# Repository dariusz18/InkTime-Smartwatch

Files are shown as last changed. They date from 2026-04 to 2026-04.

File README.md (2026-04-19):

# Documentatie Tehnica Hardware - InkTime Smartwatch

Acest repository contine fisierele de proiectare hardware pentru InkTime, un dispozitiv purtabil bazat pe arhitectura nRF52840, optimizat pentru eficienta energetica ridicata si afisaj bi-stabil.

## 1. Descriere Functionalitate Hardware

Sistemul electronic este proiectat modular, avand urmatoarele subsisteme critice:

* **Unitatea Centrala de Procesare (MCU):** Proiectul utilizeaza SoC-ul **nRF52840** (Nordic Semiconductor), ales pentru suportul nativ Bluetooth 5.0 si consumul minim in modurile de repaus. Acesta gestioneaza comunicarea cu senzorii si controlul refresh-ului pentru display.
* **Modulul de Afisaj (E-Paper):** Dispozitivul integreaza un ecran tip Electronic Paper (e-Ink). Circuitul de comanda include un convertor de tip "boost" (format din inductanta de 68uH, diode Schottky si tranzistori MOSFET) necesar pentru generarea tensiunilor de polarizare specifice tehnologiei electroforetice.
* **Managementul Alimentarii (PMU):** * **LiPo Charger:** Incarcarea acumulatorului este gestionata de un controller dedicat, configurat pentru curent de incarcare sigur.
    * **DC/DC Converter:** Asigura conversia tensiunii bateriei la pragul stabil de 3.3V necesar rail-ului digital.
    * **Fuel Gauge:** Integratul MAX17048 monitorizeaza starea de sanatate a bateriei si transmite datele prin I2C.
* **Interfata cu Utilizatorul:** Sistemul include trei butoane mecanice conectate la pini GPIO cu pull-up intern si un driver haptic pentru semnalizarea evenimentelor prin vibratii.

## 2. Diagrama Bloc si Conectivitate

Arhitectura sistemului urmeaza fluxul: **Sursa Energie -> PMU -> MCU -> Periferice (Display/IMU)**.

### Tabel Conectare Pini nRF52840

| Periferic | Protocol Comunicare | Pini Alocati (MCU) |
| :--- | :--- | :--- |
| **E-Paper Display** | SPI (MOSI, SCK, CS) | P0.26, P0.27 (DC), P0.28 (RES) |
| **IMU / Fuel Gauge** | I2C (SDA, SCL) | P0.11, P0.12 |
| **Haptic Motor** | PWM | P0.14 |
| **Butoane (Up/Ent/Dn)** | Digital Input | P0.09, P0.10, P0.24 |
| **Programare/Debug** | SWD | SWDIO, SWDCLK |

## 3. Implementare Mecanica si Proiectare 3D

Carcasa proiectata in Autodesk Fusion asigura protectia mecanica a ansamblului. Proiectarea a tinut cont de:
* Pozitionarea antenei nRF52840 departe de planul de masa pentru semnal optim.
* Asamblarea tip "sandwich" a componentelor: Ecran -> PCB -> Baterie.
* Accesul extern pentru portul de incarcare USB-C, protejat prin circuite de suprimare a tensiunilor tranzitorii (TVS/ESD).

### Review Tehnologic: Avantajele tehnologiei E-Paper
Alegerea unui afisaj de tip E-Paper ofera dispozitivului o autonomie superioara. Datorita proprietatii de bi-stabilitate, pixelii isi mentin starea fara consum de energie. Consumul de curent are loc exclusiv in timpul tranzitiilor de stare (refresh), permitand MCU-ului sa ramana in mod "Deep Sleep" majoritatea timpului. Aceasta abordare elimina necesitatea unei iluminari de fundal (Backlight), vizibilitatea fiind direct proportionala cu lumina ambientala.

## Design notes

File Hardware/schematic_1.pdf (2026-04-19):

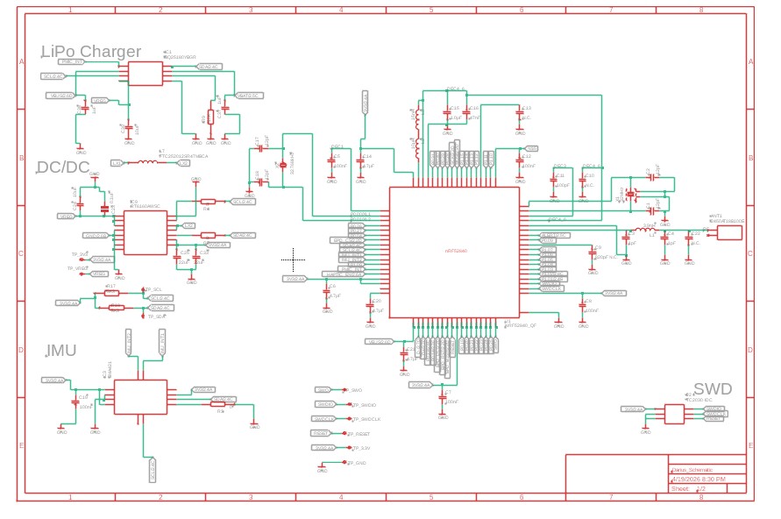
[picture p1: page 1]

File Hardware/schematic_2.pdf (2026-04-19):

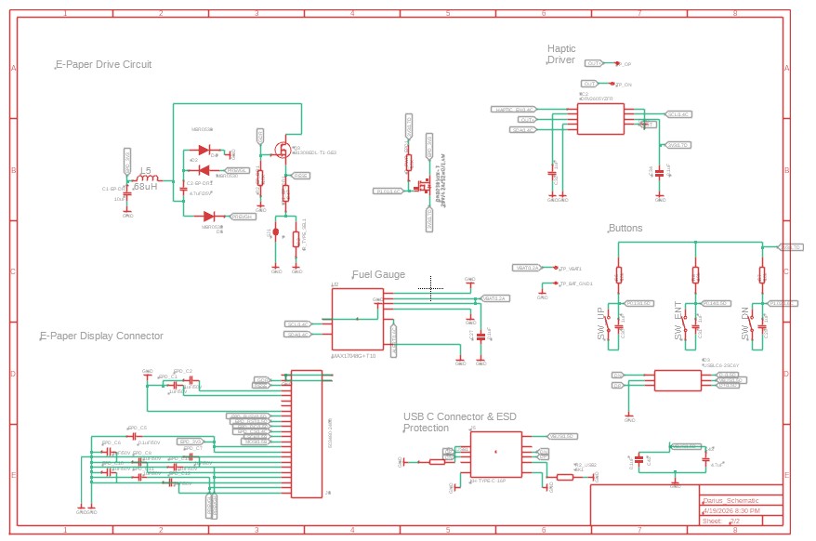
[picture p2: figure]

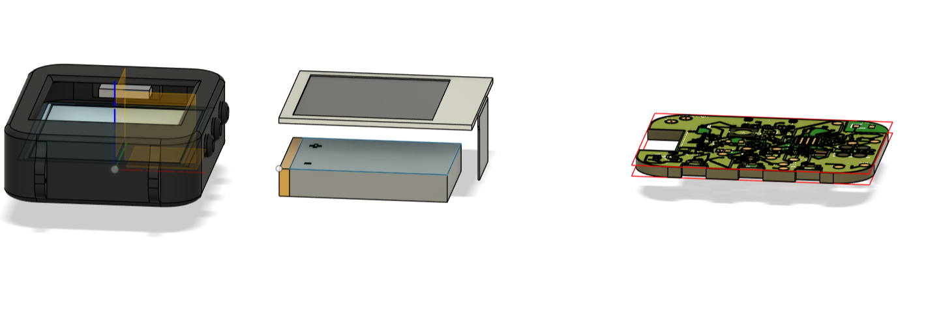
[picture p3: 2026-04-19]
Images/Screenshot 2026-04-20 000259.png

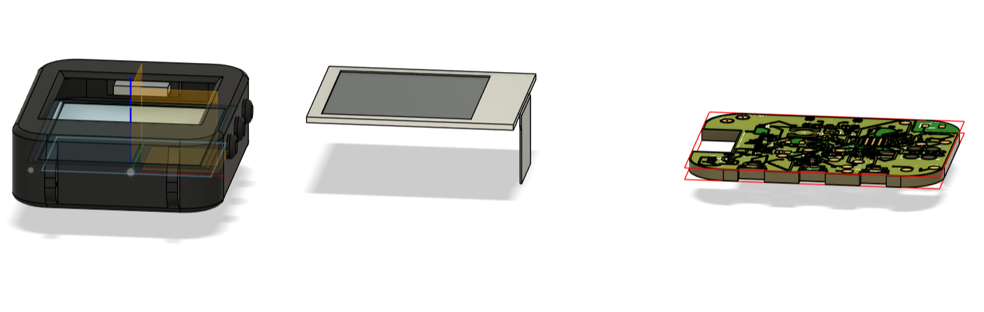
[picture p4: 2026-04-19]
Images/Screenshot 2026-04-20 000249.png

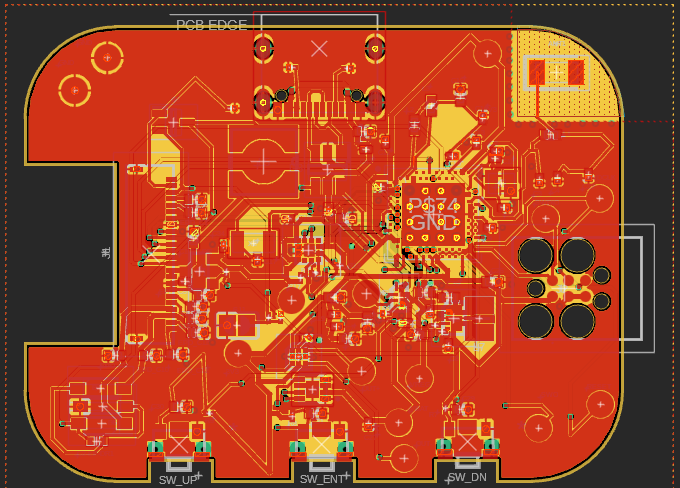
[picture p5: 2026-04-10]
Images/pcb.png

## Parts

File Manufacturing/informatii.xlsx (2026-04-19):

Name | Zaharescu
Exported by | darius.zaharescu@stud.acs.upb.ro
Time of Export | 4/20/2026 12:54 AM
Reference Designators | Quantity | Description | Package | Value | Manufacturer | Manufacturer Part Number | Vendor | Vendor Part Number | Top/Bottom
 | 1 | PCB Board | Board
ANT1 | 1 | 2450AT18B100E-1 | 2450AT18B100E_ANTC3216X140N | 2450AT18B100E |  |  |  |  | Top
C1, C2, C17, C18 | 4 | 0201 chip | NORDIC_NRF_3_RESC0201_L | 12pF |  |  |  |  | Top
C1-EP-DR, C24, C39 | 3 | 0402 chip | NORDIC_NRF_3_RESC0402_L | 10uF |  |  |  |  | Top
C2-EP-DR1 | 1 | 0402 chip | NORDIC_NRF_3_RESC0402_L | 4.7uF/25V |  |  |  |  | Top
C3, C4 | 2 | 0201 chip | NORDIC_NRF_3_RESC0201_L | 1pF |  |  |  |  | Top
C5, C7, C8, C12, C19 | 5 | 0201 chip | NORDIC_NRF_3_RESC0201_L | 100nF |  |  |  |  | Top
C6, C14, C20, C21 | 4 | 0402 chip | NORDIC_NRF_3_RESC0402_L | 4.7µF |  |  |  |  | Top
C9 | 1 | 0201 chip | NORDIC_NRF_3_RESC0201_L | 820pF |  |  |  |  | Top
C10, C13 | 2 | 0201 chip | NORDIC_NRF_3_RESC0201_L |  |  |  |  |  | Top
C11 | 1 | 0201 chip | NORDIC_NRF_3_RESC0201_L | 100pF |  |  |  |  | Top
C15 | 1 | 0402 chip | NORDIC_NRF_3_RESC0402_L | 1.0µF |  |  |  |  | Top
C16 | 1 | 0201 chip | NORDIC_NRF_3_RESC0201_L | 47nF |  |  |  |  | Top
C22 | 1 | 0201 chip | NORDIC_NRF_3_RESC0201_L | N.C. |  |  |  |  | Top
C23, C27, C42 | 3 | 0201 chip | NORDIC_NRF_3_RESC0201_L | 0.1uF |  |  |  |  | Top
C25, C33 | 2 | 0402 chip | NORDIC_NRF_3_RESC0402_L | 22uF |  |  |  |  | Top
C29, C30, C31 | 3 | 0402 chip | NORDIC_NRF_3_RESC0402_L | 1uF |  |  |  |  | Top
C32, C37, C38 | 3 |  | GRM011R60J152KE01L_2_CAPC0201X13N | 1uF |  |  |  |  | Top
C34 | 1 |  | GRM011R60J152KE01L_2_CAPC0201X13N | 0.1uF |  |  |  |  | Top
C43 | 1 | 0402 chip | NORDIC_NRF_3_RESC0402_L | 4.7uF |  |  |  |  | Top
D2, D4, D5 | 3 | SOD-123 CASE425-04 ISSUE G | ESP32_C6_LIBRARY_5_SOD3716X135N | MBR0530 |  |  |  |  | Top
D3 | 1 | SOT23-6(ESDA6V1-5SC6Y) | ESP32_C6_LIBRARY_3_SOT95P280X145-6N | USBLC6-2SC6Y |  |  |  |  | Top
EPD_C1, EPD_C2, EPD_C6, EPD_C7, EPD_C8, EPD_C9, EPD_C10, EPD_C11, EPD_C12 | 9 | 0402 chip | NORDIC_NRF_3_RESC0402_L | 1uF/50V |  |  |  |  | Top
EPD_C5 | 1 | 0201 chip | NORDIC_NRF_3_RESC0201_L | 0.1uF/50V |  |  |  |  | Top
IC1 | 1 | YBG0008 | BQ25180YBGR_BGA8C40P2X4_100X155X50 | BQ25180YBGR |  |  |  |  | Top
IC2 | 1 | DRV2605YZFR_1 | DRV2605YZFR_BGA9C50P3X3_144X144X62 | DRV2605YZFR |  |  |  |  | Top
IC3 | 1 | BMA423-1 | BMA423_BMA423 | BMA423 |  |  |  |  | Top
IC9 | 1 | 15B WL-CSP 1.4x2.3 Package (BSC) | RT6160AWSC_BGA15C40P3X5_140X230X60 | RT6160AWSC |  |  |  |  | Top
J1 | 1 | 503480-2400-2 | 503480-2400_5034802400 | 503480-2400 |  |  |  |  | Top
J2 | 1 | TC2030-IDC | TC2030-IDC_TC2030IDC | TC2030-IDC |  |  |  |  | Top
J4 | 1 |  | KH-TYPE-C-16P_KINGHELM_KH-TYPE-C-16P | KH-TYPE-C-16P |  |  |  |  | Top
L1 | 1 | 0402 chip | NORDIC_NRF_2_RESC0402_L | 3.9nH |  |  |  |  | Top
L2 | 1 | 0402 chip | NORDIC_NRF_2_RESC0402_L | 10µH |  |  |  |  | Top
L3 | 1 | 0402 chip | NORDIC_NRF_2_RESC0402_L | 15nF |  |  |  |  | Top
L5 | 1 |  | ESP32_C6_LIBRARY_2_IND_4828-WE-TPC_WRE | 68uH |  |  |  |  | Top
L7 | 1 | MLP2016 | MLP2016SR47MT0S1_INDC2016X100N | FTC252012SR47MBCA |  |  |  |  | Top
Q1 | 1 | SOT23-3X | ESP32_C6_LIBRARY_4_ESP32_C6_LIBRARY_4_ESP32_C6_LIBRARY_4_ESP32_C6_LIBRARY_4_ESP32_WROVER_SPARKFUN-DISCRETESEMI_SOT23-3 | 20V/4.2A/52mΩ/1.4W |  |  |  |  | Top
Q3 | 1 | SC-70_3LEADS | ESP32_C6_LIBRARY_6_SOT65P210X110-3N | SI1308EDL-T1-GE3 |  |  |  |  | Top
R_PWR_EPD, R2_EP_DR, R9 | 3 |  | CPF0201D7K68C1_0201 | 10K |  |  |  |  | Top
R_TYPE_SEL | 1 |  | CPF0201D7K68C1_0201 | 2.2 |  |  |  |  | Top
R1_EP_DR | 1 |  | CPF0201D7K68C1_0201 | 0.47 |  |  |  |  | Top
R1_USB, R2_USB | 2 |  | ERA-1AEB3401C_0201 | 5K1 |  |  |  |  | Top
R2, R3, R4 | 3 |  | CPF0201D7K68C1_0201 | CPF0201D7K68C1_CPF0201D7K68C1 |  |  |  |  | Top
R5, R7, R8 | 3 |  | CPF0201D7K68C1_0201 | 10k |  |  |  |  | Top
R17, R18 | 2 |  | CPF0201D7K68C1_0201 | 3K3 |  |  |  |  | Top
SJ1 | 1 | Solder jumper | ESP32_C6_LIBRARY_7_JUMPER_SJ |  |  |  |  |  | Top
SW_DN, SW_UP | 2 |  | 2025-10-22_07-23-44_LIBRARY_SW_EVP-AKE31A_PAN | 2025-10-22_07-23-44_LIBRARY_EVP-AKE31ASW_EVP-AKE31A_PAN |  |  |  |  | Top
SW_ENT | 1 |  | 2025-10-22_07-23-44_LIBRARY_SW_EVP-AKE31A_PAN | SW_ENT |  |  |  |  | Top
TP_3V3, TP_BAT_GND, TP_ON, TP_OP, TP_SCL, TP_SDA, TP_VBAT, TP_VREG, TP1, TP2, TP3, TP4, TP5, TP6 | 14 | TEST PAD | HECTOR_WATCH_1_TP20R | HECTOR_WATCH_1_TPTP20R |  |  |  |  | Top
U1 | 1 |  | NORDIC_NRF_4_AQFN50P700X700X85_HS-74N | NRF52840_QF |  |  |  |  | Top
U3 | 1 |  | ESP32_C6_LIBRARY_SON50P200X200X80-9N | MAX17048G+T10 |  |  |  |  | Top
X1 | 1 | BT-XTAL_2016 | NORDIC_NRF_BT-XTAL_2016_N | 32MHz |  |  |  |  | Top
X2 | 1 | XTAL_3215 | NORDIC_NRF_1_XTAL_3215_N | 32.768kHz |  |  |  |  | Top

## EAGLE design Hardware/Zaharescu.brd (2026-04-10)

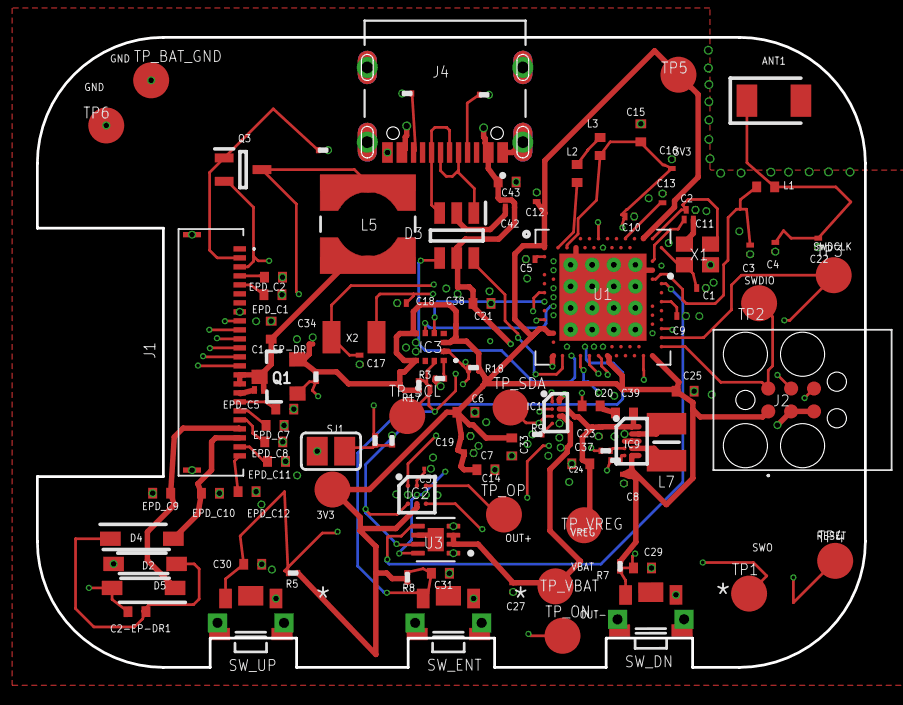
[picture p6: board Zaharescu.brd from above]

Board: 4 copper layers, 46.0 x 35.0 mm, 105 parts (0 on the bottom side), 70 nets.

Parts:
ANT1: 2450AT18B100E; 2450AT18B100E_ANTC3216X140N
C1, C2, C17, C18: 12pF; NORDIC_NRF_3_RESC0201_L
C1-EP-DR, C24, C39: 10uF; NORDIC_NRF_3_RESC0402_L
C2-EP-DR1: 4.7uF/25V; NORDIC_NRF_3_RESC0402_L
C3, C4: 1pF; NORDIC_NRF_3_RESC0201_L
C5, C7, C8, C12, C19: 100nF; NORDIC_NRF_3_RESC0201_L
C6, C14, C20, C21: 4.7µF; NORDIC_NRF_3_RESC0402_L
C9: 820pF; NORDIC_NRF_3_RESC0201_L
C10, C13: NORDIC_NRF_3_RESC0201_L
C11: 100pF; NORDIC_NRF_3_RESC0201_L
C15: 1.0µF; NORDIC_NRF_3_RESC0402_L
C16: 47nF; NORDIC_NRF_3_RESC0201_L
C22: N.C.; NORDIC_NRF_3_RESC0201_L
C23, C27, C42: 0.1uF; NORDIC_NRF_3_RESC0201_L
C25, C33: 22uF; NORDIC_NRF_3_RESC0402_L
C29, C30, C31: 1uF; NORDIC_NRF_3_RESC0402_L
C32, C37, C38: 1uF; GRM011R60J152KE01L_2_CAPC0201X13N
C34: 0.1uF; GRM011R60J152KE01L_2_CAPC0201X13N
C43: 4.7uF; NORDIC_NRF_3_RESC0402_L
D2, D4, D5: MBR0530; ESP32_C6_LIBRARY_5_SOD3716X135N
D3: USBLC6-2SC6Y; ESP32_C6_LIBRARY_3_SOT95P280X145-6N
EPD_C1, EPD_C2, EPD_C6, EPD_C7, EPD_C8, EPD_C9, EPD_C10, EPD_C11, EPD_C12: 1uF/50V; NORDIC_NRF_3_RESC0402_L
EPD_C5: 0.1uF/50V; NORDIC_NRF_3_RESC0201_L
IC1: BQ25180YBGR; BQ25180YBGR_BGA8C40P2X4_100X155X50
IC2: DRV2605YZFR; DRV2605YZFR_BGA9C50P3X3_144X144X62
IC3: BMA423; BMA423_BMA423
IC9: RT6160AWSC; RT6160AWSC_BGA15C40P3X5_140X230X60
J1: 503480-2400; 503480-2400_5034802400
J2: TC2030-IDC; TC2030-IDC_TC2030IDC
J4: KH-TYPE-C-16P; KH-TYPE-C-16P_KINGHELM_KH-TYPE-C-16P
L1: 3.9nH; NORDIC_NRF_2_RESC0402_L
L2: 10µH; NORDIC_NRF_2_RESC0402_L
L3: 15nF; NORDIC_NRF_2_RESC0402_L
L5: 68uH; ESP32_C6_LIBRARY_2_IND_4828-WE-TPC_WRE
L7: FTC252012SR47MBCA; MLP2016SR47MT0S1_INDC2016X100N
Q1: 20V/4.2A/52mΩ/1.4W; ESP32_C6_LIBRARY_4_ESP32_C6_LIBRARY_4_ESP32_C6_LIBRARY_4_ES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
Q3: SI1308EDL-T1-GE3; ESP32_C6_LIBRARY_6_SOT65P210X110-3N
R1_EP_DR: 0.47; CPF0201D7K68C1_0201
R1_USB, R2_USB: 5K1; ERA-1AEB3401C_0201
R2, R3, R4: CPF0201D7K68C1_CPF0201D7K68C1; CPF0201D7K68C1_0201
R2_EP_DR, R9: 10K; CPF0201D7K68C1_0201
R5, R7, R8: 10k; CPF0201D7K68C1_0201
R17, R18: 3K3; CPF0201D7K68C1_0201
R_PWR_EPD: 10K; CPF0201D7K68C1_0201
R_TYPE_SEL: 2.2; CPF0201D7K68C1_0201
SJ1: ESP32_C6_LIBRARY_7_JUMPER_SJ
SW_DN: 2025-10-22_07-23-44_LIBRARY_EVP-AKE31ASW_EVP-AKE3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; 2025-10-22_07-23-44_LIBRARY_SW_EVP-AKE31A_PAN
SW_ENT: SW_ENT; 2025-10-22_07-23-44_LIBRARY_SW_EVP-AKE31A_PAN
SW_UP: 2025-10-22_07-23-44_LIBRARY_EVP-AKE31ASW_EVP-AKE3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; 2025-10-22_07-23-44_LIBRARY_SW_EVP-AKE31A_PAN
TP1, TP2, TP3, TP4, TP5, TP6: HECTOR_WATCH_1_TPTP20R; HECTOR_WATCH_1_TP20R
TP_3V3: HECTOR_WATCH_1_TPTP20R; HECTOR_WATCH_1_TP20R
TP_BAT_GND: HECTOR_WATCH_1_TPTP20R; HECTOR_WATCH_1_TP20R
TP_ON: HECTOR_WATCH_1_TPTP20R; HECTOR_WATCH_1_TP20R
TP_OP: HECTOR_WATCH_1_TPTP20R; HECTOR_WATCH_1_TP20R
TP_SCL: HECTOR_WATCH_1_TPTP20R; HECTOR_WATCH_1_TP20R
TP_SDA: HECTOR_WATCH_1_TPTP20R; HECTOR_WATCH_1_TP20R
TP_VBAT: HECTOR_WATCH_1_TPTP20R; HECTOR_WATCH_1_TP20R
TP_VREG: HECTOR_WATCH_1_TPTP20R; HECTOR_WATCH_1_TP20R
U1: NRF52840_QF; NORDIC_NRF_4_AQFN50P700X700X85_HS-74N
U3: MAX17048G+T10; ESP32_C6_LIBRARY_SON50P200X200X80-9N
X1: 32MHz; NORDIC_NRF_BT-XTAL_2016_N
X2: 32.768kHz; NORDIC_NRF_1_XTAL_3215_N

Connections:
3V3: C6.1, C7.1, C8.1, C12.1, C14.1, C19.1, C25.1, C33.1, C34.2, IC2.C2, IC3.3, IC3.7, IC3.10, IC9.E2, IC9.E3, J2.1, Q1.2, R5.2, R7.2, R8.2, R17.1, R18.1, R_PWR_EPD.2, TP5.TP, TP_3V3.TP, U1.P$A22, U1.P$AD14, U1.P$AD23, U1.P$B1, U1.P$W1, U1.P$Y2
ALERT: U1.P$J24, U3.5
D+: D3.4, U1.P$AD6
D-: D3.6, U1.P$AD4
DN: D3.1, J4.A7, J4.B7
DP: D3.3, J4.A6, J4.B6
EPD_3V3: C1-EP-DR.1, EPD_C5.2, J1.15, J1.16, L5.2, Q1.3
EPD_BUSY: J1.9, U1.P$AD12
EPD_CS: J1.12, U1.P$K2
EPD_DC: J1.11, U1.P$AD10
EPD_RST: J1.10, U1.P$AC11
GDR: J1.2, Q3.1, R2_EP_DR.2
GND: C1.2, C1-EP-DR.2, C2.2, C3.2, C4.2, C5.2, C6.2, C7.2, C8.2, C9.2, C10.1, C11.2, C12.2, C13.1, C14.2, C15.2, C16.2, C17.1, C18.1, C19.2, C20.2, C21.2, C22.2, C23.1, C24.1, C25.2, C27.2, C29.2, C30.2, C31.2, C32.1, C33.2, C34.1, C37.1, C38.1, C39.2, C42.2, C43.2, D2.1, D3.2, EPD_C1.1, EPD_C2.1, EPD_C5.1, EPD_C6.1, EPD_C7.1, EPD_C8.1, EPD_C9.1, EPD_C10.1, EPD_C11.1, EPD_C12.1, IC1.D2, IC2.B1, IC2.B3, IC3.8, IC3.9, IC9.B1, IC9.C1, IC9.C2, IC9.C3, J1.8, J1.17, J1.MP1, J1.MP2, J2.3, J2.5, J4.A1_B12, J4.A12_B1, J4.SH1, J4.SH2, J4.SH3, J4.SH4, R1_USB.1, R2_EP_DR.1, R2_USB.2, R3.1, R9.1, R_TYPE_SEL.1, SJ1.1, SW_DN.1, SW_ENT.1, SW_UP.1, TP6.TP, TP_BAT_GND.TP, U1.P$74, U1.P$75, U1.P$76, U1.P$77, U1.P$78, U1.P$79, U1.P$80, U1.P$81, U1.P$82, U1.P$83, U1.P$84, U1.P$85, U1.P$86, U1.P$87, U1.P$88, U1.P$89, U1.P$90, U1.P$B7, U1.P$F23, U3.1, U3.4, U3.6, U3.9, X1.2, X1.4
HAPTIC_EN: IC2.A1, U1.P$U1
IMU_INT1: IC3.5, U1.P$N1
IMU_INT2: IC3.6, U1.P$P2
LX1: IC9.B2, IC9.B3, L7.1
LX2: IC9.D2, IC9.D3, L7.2
MOSI: J1.14, U1.P$B13
unnamed: C5.1, U1.P$C1
unnamed: C9.1, U1.P$N24
unnamed: C11.1, U1.P$D23
unnamed: IC9.D1, R4.2
unnamed: C17.2, U1.P$D2, X2.2
unnamed: C18.2, U1.P$F2, X2.1
unnamed: C2-EP-DR1.2, D5.2, L5.1, Q3.3
unnamed: C3.1, L1.1, U1.P$H23
unnamed: ANT1.1, C4.1, C22.1, L1.2
unnamed: C10.2, C15.1, C16.1, L3.1, U1.P$B5, U1.P$E24
unnamed: C2.1, U1.P$A23, X1.3
unnamed: C1.1, U1.P$B24, X1.1
unnamed: L2.1, L3.2
unnamed: L2.2, U1.P$B3
unnamed: C13.2, U1.P$A18
unnamed: IC3.1, R3.2
unnamed: C20.1, U1.P$AC5
unnamed: IC9.E1, R2.2
unnamed: EPD_C8.2, J1.20
unnamed: IC1.D1, R9.2
unnamed: C2-EP-DR1.1, D2.2, D4.1
unnamed: EPD_C2.2, J1.4
unnamed: R1_EP_DR.1, R_TYPE_SEL.2, SJ1.2
unnamed: EPD_C1.2, J1.5
unnamed: C32.2, IC2.A2
unnamed: J4.B5, R2_USB.1
unnamed: J4.A5, R1_USB.2
unnamed: EPD_C7.2, J1.19
unnamed: EPD_C6.2, J1.18
unnamed: EPD_C11.2, J1.23
unnamed: EPD_C12.2, J1.24
OUT+: IC2.A3, TP_OP.TP
OUT-: IC2.C3, TP_ON.TP
P0.13: C30.1, R5.1, SW_UP.2, U1.P$AD8
P0.14: C31.1, R8.1, SW_ENT.2, U1.P$AC9
P1.01: Q1.1, R_PWR_EPD.1, U1.P$Y23
P1.02: C29.1, R7.1, SW_DN.2, U1.P$W24
PMIC_INT: IC1.A1, U1.P$T2
PREVGH: D5.1, EPD_C9.2, J1.21
PREVGL: D4.2, EPD_C10.2, J1.22
RESE: J1.3, Q3.2, R1_EP_DR.2
RESET: J2.6, TP4.TP, U1.P$AC13
SCK: J1.13, U1.P$A12
SCL: IC1.B1, IC2.C1, IC3.12, R4.1, R17.2, TP_SCL.TP, U1.P$M2, U3.7
SDA: IC1.C1, IC2.B2, IC3.2, R2.1, R18.2, TP_SDA.TP, U1.P$L1, U3.8
SWDCLK: J2.4, TP3.TP, U1.P$AA24
SWDIO: J2.2, TP2.TP, U1.P$AC24
SWO: TP1.TP, U1.P$AD22
VBAT: C27.1, C37.2, IC1.C2, TP_VBAT.TP, U3.2, U3.3
VBUS: C21.1, C38.2, C42.1, C43.1, D3.5, IC1.A2, J4.A4_B9, J4.A9_B4, U1.P$AD2
VREG: C23.2, C24.2, C39.1, IC1.B2, IC9.A1, IC9.A2, IC9.A3, TP_VREG.TP

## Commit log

2026-04-10 Initial EVT commit
    [Darius_Schematic.sch, Zaharescu.brd]
2026-04-19 Am adaugat fisierele finale pentru hardware, imagini si manufacturing
    [informatii.xlsx]

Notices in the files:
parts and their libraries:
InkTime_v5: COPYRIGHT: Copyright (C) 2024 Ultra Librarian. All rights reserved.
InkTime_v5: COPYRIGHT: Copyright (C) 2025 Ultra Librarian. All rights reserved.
